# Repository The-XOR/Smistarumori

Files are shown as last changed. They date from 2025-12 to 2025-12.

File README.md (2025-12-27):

# Lo Smistarumori

Questo progetto dal nome futurista è un patchbay a 3 ingressi e 6 uscite, ma col trucco. La libidine scatta col fatto che è comandabile via MIDI, e come se non bastasse genera un codice di nota a seconda dell'entrata/uscita selezionata: cosi', se si utilizzano software di correzione si puo' cambiare preset di in base alla cuffia selezionata. In effetti, tutto questo delirio di progetto nasce proprio dalla mia pigrizia nel cambiare preset a mano.
Il circuito utilizza dei relè, quindi non ci dovrebbe essere degrado del segnale essendo la logica di controllo completamente isolata dalla parte audio senza alcun punto di contatto. Tranquillizzato l'audiofilo di turno, procediamo con la narriazione di quella che è stata una lunga gestazione.
I nomi delle entrate/uscite mostrati sul display sono configurati nel file **config.json**; per i nomi si hanno a disposizione fino a 14 caratteri. Per finire, viene memorizzata l'ultima configurazione utilizzata in modo da ritrovare attivati all' riaccensione gli stessi collegamenti.

### I Collegamenti
Così come nasce dalla mente malata di chi scrive, e principalmente poiché questa è la mia esatta configurazione, i collegamenti sono:
- Ingresso 1 va diretto all'uscita selezionata
- Gli ingressi 2 e 3 invece sono collegati con l'uscita SEND, e alle cuffie andrà il segnale in ritorno dall'entrata sorprendentemente chiamata RETURN. Tra send e return c'è un amplificatore per cuffie esterno, mentre l'entrata 1 puo' essere utilizzata per un segnale gia' amplificato.
Questo percorso di segnali è ampiamente modificabile a piacere, visto che son solo relè che si muovono...

### Preparasiun:
Collegare l RP2040-Zero al PC, premere il pulsante BOOT e collegarlo. 
Se CircuitPython non fu installato, scaricarlo da https://downloads.circuitpython.org/bin/waveshare_rp2040_zero/en_US/adafruit-circuitpython-waveshare_rp2040_zero-en_US-10.0.3.uf2 e copiarlo sul microcontrollore: si riavviera' ed ora saremo pronti a programmare il cippo. Alla bisogna, scollegare e ricollegare RP2040 finche' non appare il devais nomato CIRCUITPY.

### Librerie:
Su https://circuitpython.org/libraries scaricare il bundle di librerie compatibile con la versione CircuitPython utilizzata (la 10 al momento della scrittura di questo romanzo). Le librerie da copiare, estratte da questo file zip, sono:
- adafruit_bus_device
- adafruit_midi

Serve inoltre la libreria lcd, disponibile su: https://github.com/dhalbert/CircuitPython_LCD
La struttura finale deve essere questa:
```
  <CIRCUITPY>/
  ├── boot.py
  ├── code.py
  ├── config.json
  └── lib/
         ├── adafruit_bus_device
         ├── adafruit_midi
         └── lcd
```
## IMPORTANTE: usare la rimozione sicura una volta copiati i file! ##

Se qualcosa dovesse andare storto, si puo' resettare tutto avviando  RP2040 in boot mode e scopiazzandovi sopra il file **flash_nuke.uf2** disponibile su https://github.com/dwelch67/raspberrypi-pico/blob/main/flash_nuke.uf2 e non scordandosi di ricordare di compiare nuovamente anche il CircuitPython.

### Circuito elettronico
Se si hanno braccia a T-Rex e si vuole risparmiare qualche soldino (oppure semplicemente ci si vuole semplificare la vita), è possibile eliminare dal circuito gli integrati 7400 e praticamente tutti i componeti (transistor, resistenze, led, ecc.); il circuito funzionera' lo stesso, ma senza nessuna soddisfazione estetica. I componenti utilizzati sono tutti desumibili dallo schema elettrificato e dalle varie illustrazioni presenti in questa repository, il transistor è un comune PNP e può (credo) essere rimpiazzato da un altro PNP qualsiasi.

### Scatolame
La scatola (per lo iutiuber itagliota, "Lo Scatolo") è progettata secondo il materiale elencato qui sotto. Se si cambiano i tipi di tasti, il display o altro è oltremodo ovvio che la progettazione andra' rivista. I file di progettazione in formato originale sono Freecad, e questa è abbastanza parametrica: tutte le misure sono nel file **Dimensioni.FCStd**.
Per tenere i LED alla giusta altezza, con riferimento ai pulsanti utilizzati, ci sono da stampare in 3D degli appositi distanziali (file **Rialzo led.FCStd**).

### Il materiale di partenza
Tutta roba rigorosamente cinese e a basso costo, così come le finanze imponevano. Tutto comprato da Aliexpress, ma si possono trovare componenti equivalenti ovunque.

- Pulsante:
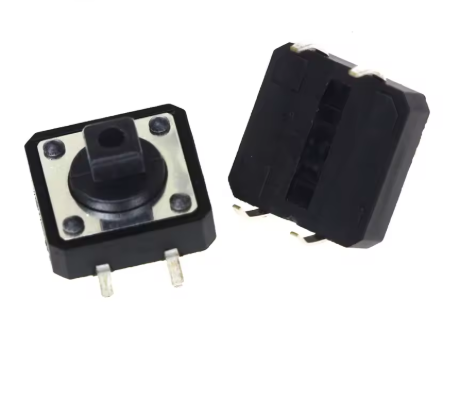
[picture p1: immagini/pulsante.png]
Pulsante

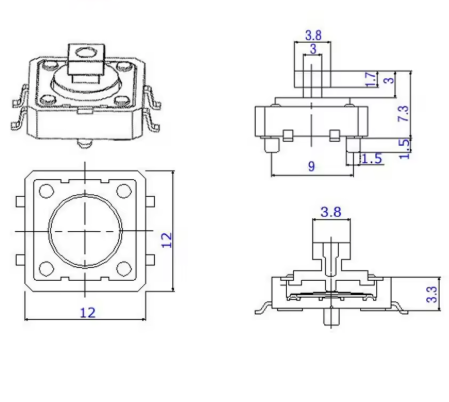
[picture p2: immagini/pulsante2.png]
Dimensioni pulsante


- Copricoso:
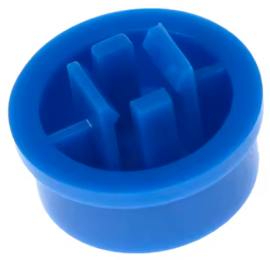
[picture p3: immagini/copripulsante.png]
Copripulsante


- LCD (2x16 caratteri), controller I2C tipo PCF8574:
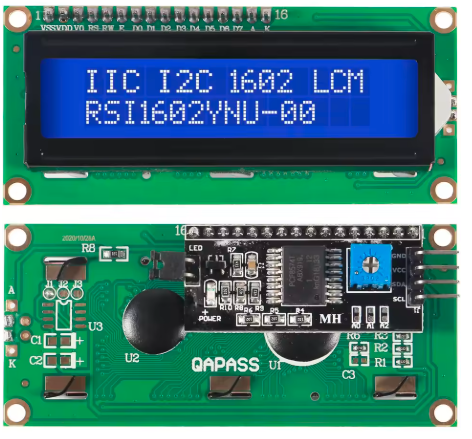
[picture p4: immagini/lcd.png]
LCD


- Scheda relais: 8 relay a 5 voltaggi
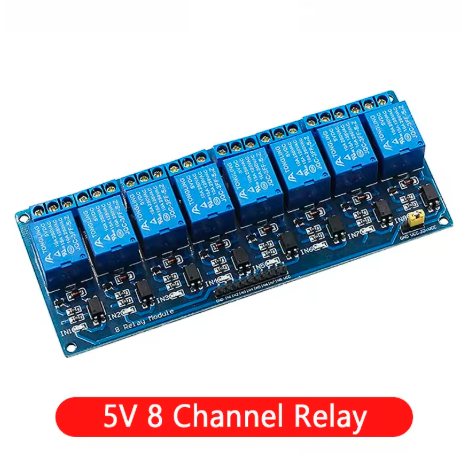
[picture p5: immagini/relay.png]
Relais


- RP2040 Zero
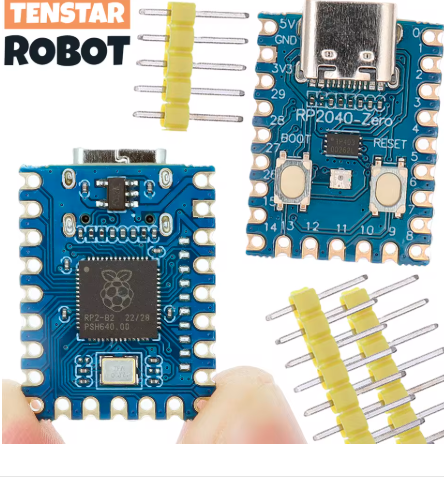
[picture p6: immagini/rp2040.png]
Microcontrollore


Elenco componenti:
- n.1 RP2040-Zero (quello piccolino con 23 pin)
- n.10 diodi led (6 di un colore per le uscite, 3 di un altro colore per le entrate, 1 per attività MIDI)
- n.1 LCD 2x16 caratteri (di base è un display 1602 con sopra un controller PCF8574 che lo trasforma da parallelo a I2C)
- n.2 moduli relè da 8, alimentati a 5V. Ce ne vogliono due perchè in genere si usa un canale per ciascheduna orecchia.
- n.1	2N3906	va bene qualsiasi transistore PNP
- n.4 resistenze 470 ohm 1/4W
- n.1 resistenza da 1800-2200 ohm 1/4W
- n.1 resistenza 10000 ohm 1/4W
- n.2 SN7404
- n.9 pulsanti normalmente aperti ma chiudibili col dito

Connettori utilizzati:
- n.8 prese jack stereo da 6,3
- n.4 prese jack mono da 6,3
- n.1 presa jack stereo da 3,5

## La scheda così come mi è venuta, saldata alla meno peggio. Faccio un altro mestiere, io.
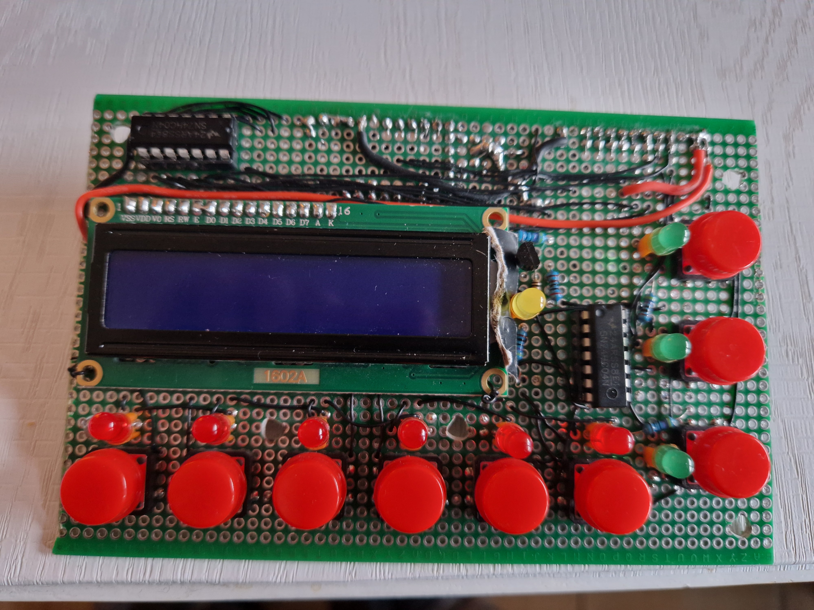
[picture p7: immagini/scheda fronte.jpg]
Scheda fronte


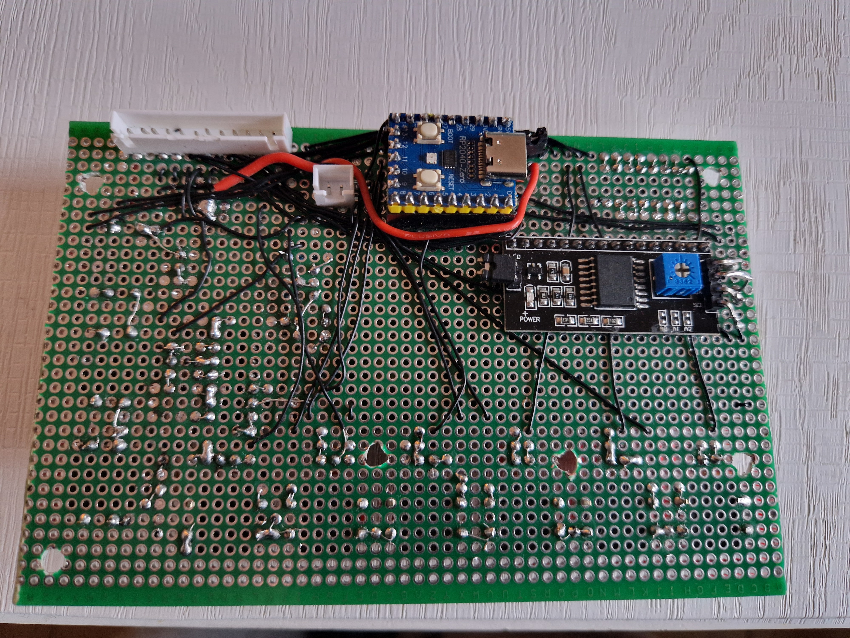
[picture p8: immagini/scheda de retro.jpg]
Scheda retro


## Il prodotto finito, così come esposto al MOMA di NY:
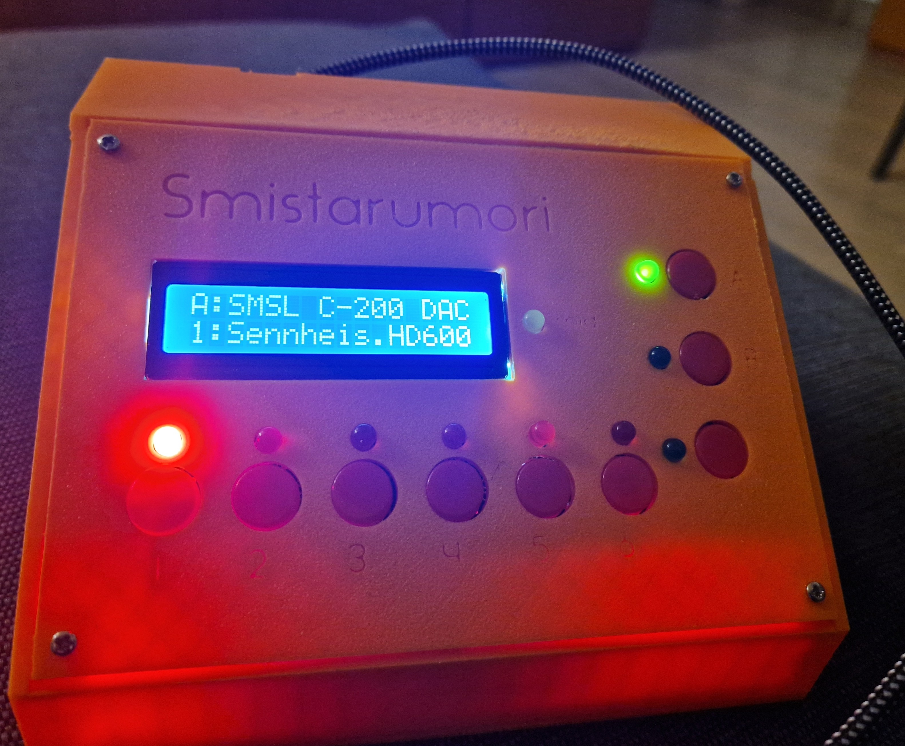
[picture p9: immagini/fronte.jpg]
Foto fronte


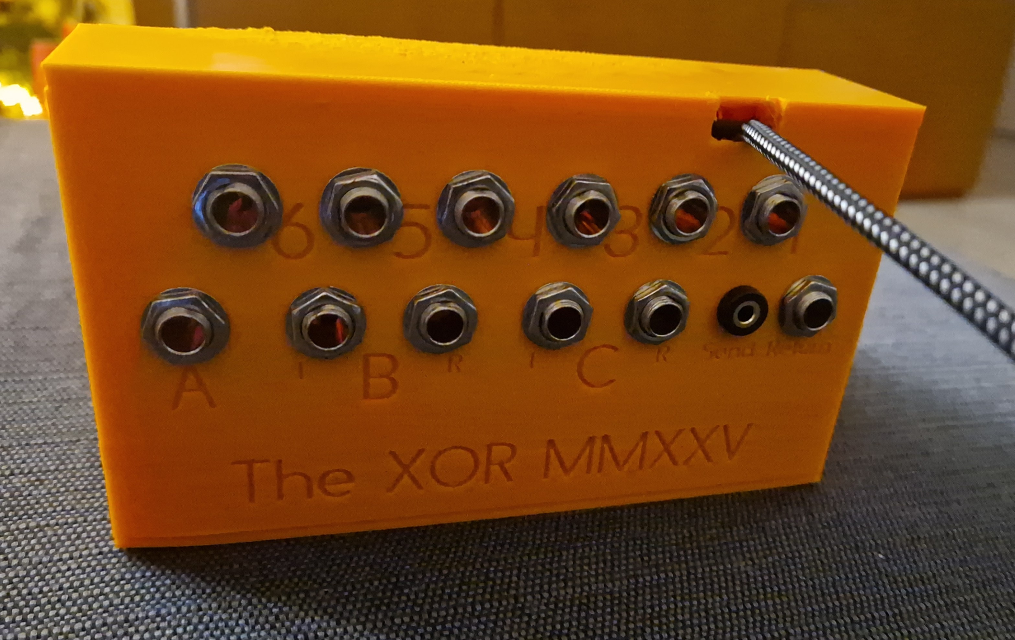
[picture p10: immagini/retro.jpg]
Foto retro


## Test finale
Una volta collegate le schede rele alla scheda principale, verificare che premendo i vari testi entrate/uscite si illuminino i rispettivi led sulle schede rele (le due schede sono collegate in parallelo, una gestisce il canale destro, una il sinistro). Quando si è sicuri che tutto funzioni, aprire direttamente sulla cartella del microcontrollore il file **boot.py** e modificare la linea:

```
MODALITA_SVILUPPO = False  # Imposta a False per abilitare la persistenza dell'ultima configurazione

```
Disabilitata la modalita' di sviluppo, il microcontrollore non sara' piu' visibile come disco dal sistema operativo. Per eventuali modifiche a qualsivoglia file, si puo':
- Seguire la via secca e resettare completamente il cippo, come narrato innanzi (flash_nuke.uf2 etc).
- Percorrere la via umida, collegando lo Smistarumori al PC tenendo premuto il tasto **Input C**. In questo modo, il disco dovrebbe riapparire, ma non funzionera' la persistenza.

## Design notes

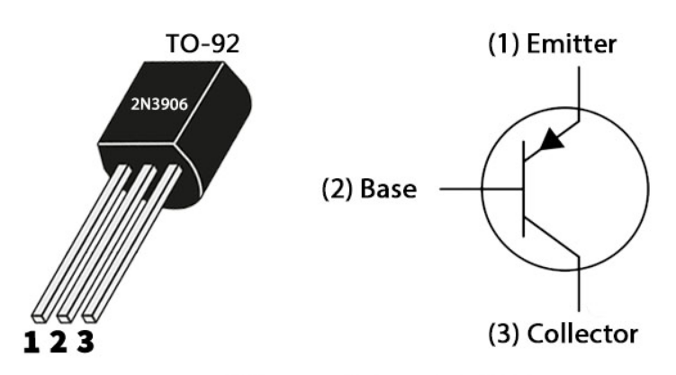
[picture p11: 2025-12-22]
schema elettrificato/2n3906.png

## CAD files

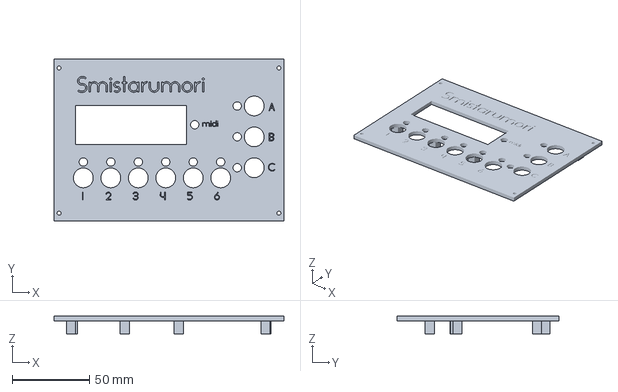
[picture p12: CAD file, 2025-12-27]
Freecad/Pannello.3mf
149.0 x 105.2 x 11.5 mm

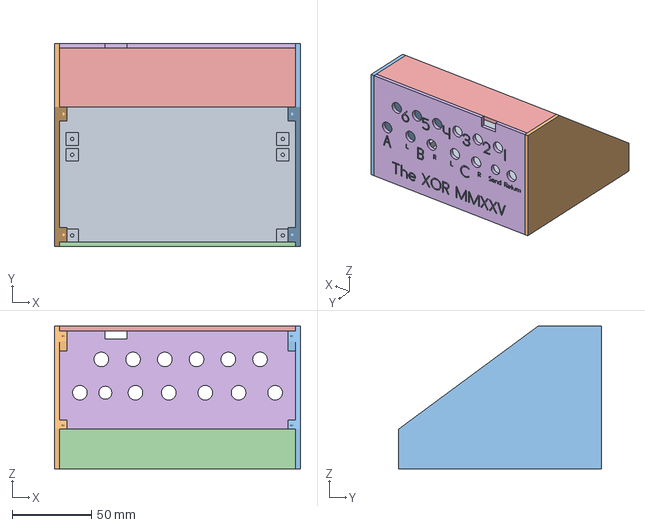
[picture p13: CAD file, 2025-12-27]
Freecad/Scatola.3mf
155.0 x 128.0 x 90.0 mm

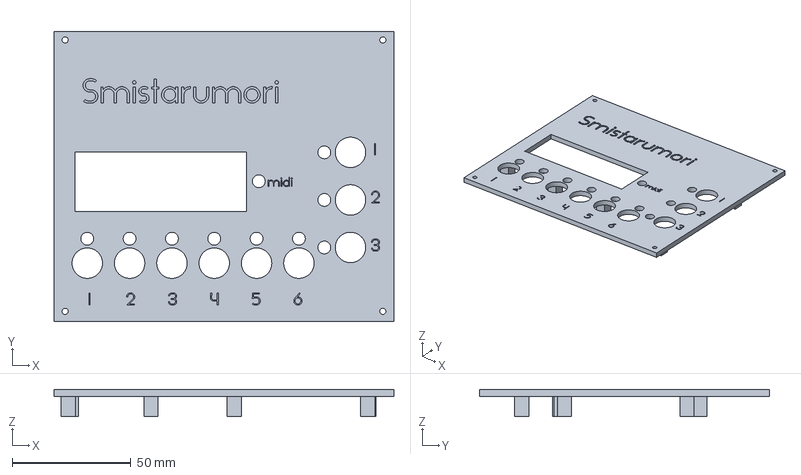
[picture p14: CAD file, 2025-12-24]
Freecad/Frontale.FCStd
143.0 x 122.0 x 11.5 mm

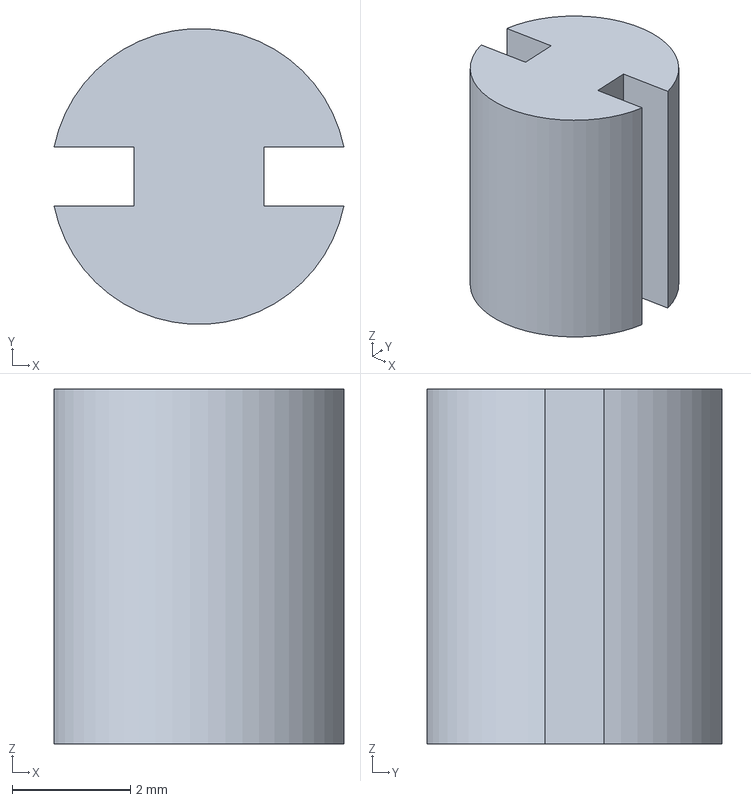
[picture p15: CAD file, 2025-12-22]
Freecad/Rialzo led.FCStd
4.90 x 4.99 x 6.00 mm

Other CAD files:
Freecad/Dimensioni.FCStd

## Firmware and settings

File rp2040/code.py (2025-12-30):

import board
import busio
import digitalio
import json
import os
import time
import usb_midi
import adafruit_midi
from adafruit_midi.note_on import NoteOn
from lcd.lcd import LCD
from lcd.i2c_pcf8574_interface import I2CPCF8574Interface

FW_VERSION = "1.0"
RELE_ACCESO = False # il modulo rele funiona a logica inversa
MIDI_ACTIVITY_ON = False
PERSISTENZA = False

# Configurazione pin rele (GP0-GP7)
rele_pins = []
for i in range(8):
    pin = digitalio.DigitalInOut(getattr(board, f'GP{i}'))
    pin.direction = digitalio.Direction.OUTPUT
    pin.value = not RELE_ACCESO 
    rele_pins.append(pin)

# I/O
midi_activity = digitalio.DigitalInOut(getattr(board, f'GP27'))
midi_activity.direction = digitalio.Direction.OUTPUT
midi_activity.value = not MIDI_ACTIVITY_ON

# Configurazione pulsanti (GP8-GP16) con pull-up
# GP8-GP13 i primi 6 pulsanti selezionano l'uscita da utilizzare
# GP14-GP16 selezionano l'ingresso da utilizzare
button_pins = [0] * 9
for i in range(len(button_pins)):
    index = i+8
    if index == 16:
        index = 26
    button_pins[i] = digitalio.DigitalInOut(getattr(board, f'GP{index}'))
    button_pins[i].direction = digitalio.Direction.INPUT
    button_pins[i].pull = digitalio.Pull.UP

# IL DISPLAY VA ALIMENTATO A 5V
# I 2 PIN DELLA RETROILLUMINAZIONE VANNO PONTICELLATI TRA LORO
i2c = busio.I2C(board.GP29, board.GP28)  # SCL=GP29, SDA=GP28
# Attendi che I2C sia pronto
while not i2c.try_lock():
    pass
i2c.unlock()
lcd = LCD(I2CPCF8574Interface(i2c, 0x27), num_rows=2, num_cols=16) 

# Configurazione MIDI USB
midi = adafruit_midi.MIDI(midi_in=usb_midi.ports[0], midi_out=usb_midi.ports[1], in_channel=0, out_channel=0)

# Stato dei pulsanti (per debouncing)
last_button_states = [True] * len(button_pins)  # True = non premuto (pull-up)

def init():
    global uscitaSelezionata, ingressoSelezionato, MIDI_NOTE_BASE, nomiIngressi, nomiUscite
    global PERSISTENZA
    try:    
        f = open("ciec", "w")
        PERSISTENZA = True
        f.close()
    except Exception as e:
        print(f"Persitenza disabilitata: {e}")
        PERSISTENZA = False
        
    print(f"Modalità persistenza: {'ON' if PERSISTENZA else 'OFF'}")
   
    try:
        with open("config.json", "r") as f:
            config = json.load(f)
            ingressoSelezionato = config.get("defaultInput", 0)
            uscitaSelezionata = config.get("defaultOutput", 0)
            disabilitaPersistenza = config.get("disabilitaPersistenza", False)
            MIDI_NOTE_BASE = config.get("midiBaseNote", 60)
            nomiIngressi = config.get("inputNames", [])
            nomiUscite = config.get("outputNames", [])    
            f.close()   

        if disabilitaPersistenza:
            PERSISTENZA = False

        if PERSISTENZA:
            # Carica stato ultimo ingresso/uscita selezionati
            if file_exists("state.json"):
                with open("state.json", "r") as f:
                    state = json.load(f)
                    ingressoSelezionato = state.get("lastInput", ingressoSelezionato)
                    uscitaSelezionata = state.get("lastOutput", uscitaSelezionata)
                    print(f"Ultimo stato caricato: Ingresso {ingressoSelezionato}, Uscita {uscitaSelezionata}")
                    f.close()

        return True
    except Exception as e:
        print(f"Errore lettura configurazione: {e}")
        return False

def file_exists(filename):
    try:
        os.stat(filename)
        return True
    except OSError:
        return False
    
def lcdprint(riga1, riga2=""):
    global lcd
    lcd.clear()
    lcd.set_cursor_pos(0, 0)
    lcd.print(riga1)
    if len(riga2) > 0:
        lcd.set_cursor_pos(1, 0)
        lcd.print(riga2)

def seleziona_ingresso(num):
    global ingressoSelezionato
    print(f"Selezione ingresso {num}")
    if 0 <= num <=2:
        ingressoSelezionato = num
        if num == 0:
            rele_pins[6].value = RELE_ACCESO # (1,0) -> selezione ingresso 1
            rele_pins[7].value = not RELE_ACCESO 
        elif num == 1:
            rele_pins[6].value = not RELE_ACCESO # (0,0) -> selezione ingresso 2
            rele_pins[7].value = not RELE_ACCESO 
        elif num == 2:    
            rele_pins[6].value = not RELE_ACCESO 
            rele_pins[7].value = RELE_ACCESO # (0,1) -> selezione ingresso 3
        sendMidi_in()
        aggiorna_display()

def seleziona_uscita(num):
    global uscitaSelezionata
    if 0 <= num <= 5:
        for i in range(6):
            if i == num:
                rele_pins[i].value = RELE_ACCESO
            else:
                rele_pins[i].value = not RELE_ACCESO
        uscitaSelezionata = num
        sendMidi_Out()
        aggiorna_display()

def sendMidi_in():
    global ingressoSelezionato, nomiIngressi
    nota = MIDI_NOTE_BASE + len(rele_pins) - 2 + ingressoSelezionato
    midi.send(NoteOn(nota, 127))
    print(f"MIDI IN: Note On {nota} ingresso {nomiIngressi[ingressoSelezionato]}")

def sendMidi_Out():
    global uscitaSelezionata, nomiUscite
    nota = MIDI_NOTE_BASE + uscitaSelezionata
    midi.send(NoteOn(nota, 127))
    print(f"MIDI OUT: Note On {nota} uscita {nomiUscite[uscitaSelezionata]}")

def aggiorna_display():
    global ingressoSelezionato, nomiIngressi, uscitaSelezionata, nomiUscite
    print(f"In: {nomiIngressi[ingressoSelezionato]} Out: {nomiUscite[uscitaSelezionata]}")
    ingr = chr(65 + ingressoSelezionato)  # A, B, C
    lcdprint(f"{ingr}:{nomiIngressi[ingressoSelezionato]}", f"{uscitaSelezionata+1}:{nomiUscite[uscitaSelezionata]}")
   
def key_pressed(i):
    print(f"Premuto tasto {i}")
    if 0 <= i <= 5:
        if i != uscitaSelezionata:
            seleziona_uscita(i)
            serialize_state()
            
    elif 6 <= i <= 8:
        ingresso_num = i - 6
        if ingresso_num != ingressoSelezionato:
            seleziona_ingresso(ingresso_num)
            serialize_state()
            
def serialize_state():
    global PERSISTENZA, ingressoSelezionato, uscitaSelezionata
    if PERSISTENZA:
        try:
            with open("state.json", "w") as f:
                state = {
                    "lastInput": ingressoSelezionato,
                    "lastOutput": uscitaSelezionata
                }
                json.dump(state, f)
                f.flush()
                f.close()
                print("Stato salvato")
        except Exception as e:
            print(f"Errore salvataggio stato: {e}")            

def leggi_pulsanti():
    global last_button_states, button_pins    
    tasto_rilevato = False
    for i in range(len(button_pins)):
        current_state = button_pins[i].value      
        # Rileva pressione (transizione da HIGH a LOW con pull-up)
        if last_button_states[i] and not current_state:
            if not tasto_rilevato:
                tasto_rilevato = True   
                key_pressed(i)
                time.sleep(0.3)  # Debouncing        
        last_button_states[i] = current_state
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

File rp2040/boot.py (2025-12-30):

import supervisor
import board
import storage
import digitalio
import time
import usb_midi

supervisor.set_usb_identification("The XOR", "Smistarumori")
usb_midi.set_names(streaming_interface_name="Smistarumori MIDI", audio_control_interface_name="Smistarumori MIDI", in_jack_name="Smistarumori MIDI In", out_jack_name="Smistarumori MIDI Out"  )

# OCIO: UNA volta messa a False, NON si potrà più accedere al filesystem da PC!
# OCIO: Se si rimane fuori di casa, avviare il coso premendo il pulsante INPUT_C
MODALITA_SVILUPPO = True  # Imposta a True per abilitare la modalità sviluppo (USB mass storage attivo)

input_C = digitalio.DigitalInOut(getattr(board, f'GP26')) #input_C
input_C.direction = digitalio.Direction.INPUT
input_C.pull = digitalio.Pull.UP
time.sleep(0.1)  # Attendi un attimo per stabilizzare lo stato del pin
if not input_C.value:
   MODALITA_SVILUPPO = True
   print("OVERRIDE: rilevato tasto inputC")

if MODALITA_SVILUPPO:
    storage.remount("/", readonly=True)
    m = storage.getmount("/")
    m.label = "SMISTARUMOR"
    storage.enable_usb_drive()
else:
    storage.disable_usb_drive()
    storage.remount("/", readonly=False)
    

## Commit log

2025-12-22 beta 0.1
    [Dimensioni.FCStd, Rialzo led.FCStd, el contenitur.FCStd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]
2025-12-25 beta 2
    [Pannello.3mf]
2025-12-27 relese 1
    [Dimensioni.FCStd, Pannello.3mf, Scatola.3mf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]
